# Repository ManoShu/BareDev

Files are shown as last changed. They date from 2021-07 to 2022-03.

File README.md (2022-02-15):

# BareDev - A small, yet resourceful keyboard

An open-source, QMK-compatible, ABNT2-based 70% keyboard, focusing in a smaller footprint while retaining all the functions found on a TKL (Del and arrow keys doubling as the navigational cluster)

---

Layout:

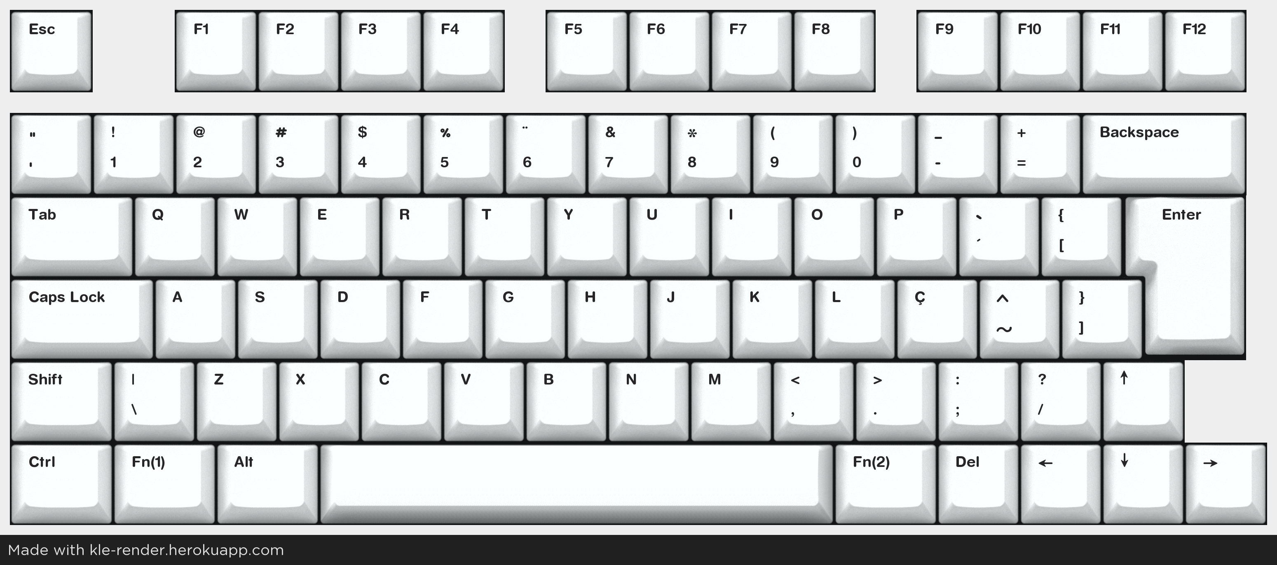
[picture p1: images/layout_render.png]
Keyboard Layout


Links: [KLE](http://www.keyboard-layout-editor.com/#/gists/89e76130aa221e028ccd5b3f6dec0909), [JSON](https://gist.github.com/ManoShu/89e76130aa221e028ccd5b3f6dec0909), [QMK](https://github.com/qmk/qmk_firmware/tree/master/keyboards/handwired/baredev/rev1)

---

## PCB & Case
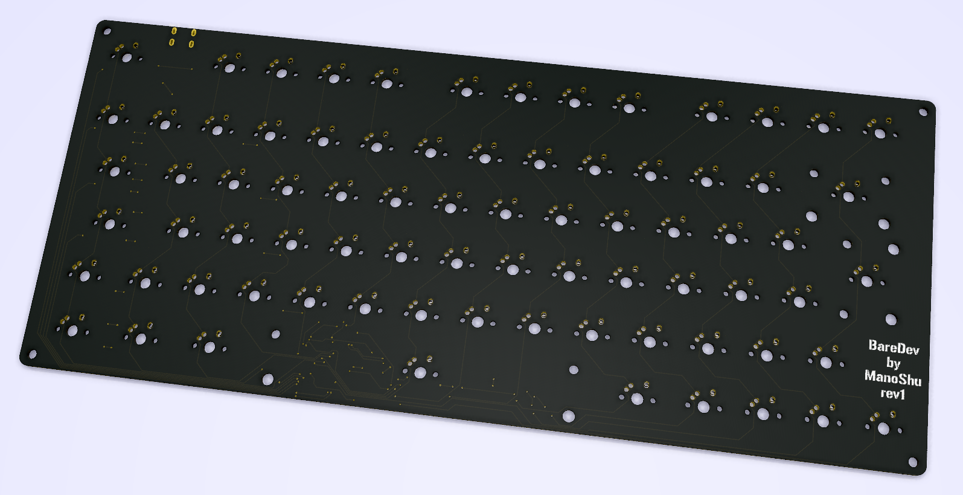
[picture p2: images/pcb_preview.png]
PCB preview on KiCad

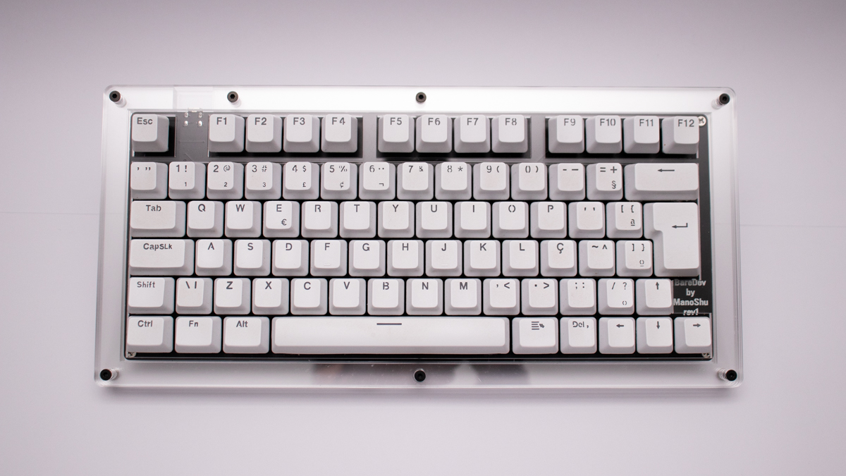
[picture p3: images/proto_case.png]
Prototype case


Note: this photo is of an early prototype of the case. The uploaded files has been updated to require less total area and WILL look slighty different than shown (the overall dimensions remain the same).

The case and gerber files are under `production`. The had been used and confirmed to work, however use them at your own risk.

## QMK

The rev1 has been integrated in the [main QMK repository](https://github.com/qmk/qmk_firmware/tree/master/keyboards/handwired/baredev/rev1), being able to use the [online configurator](https://config.qmk.fm/#/handwired/baredev/rev1/LAYOUT_abnt2) to generate the firmware while also having the files on the `qmk` directory here in case of you don't want to update your fork (HOWEVER the files have been confirmed working on QMK 0.2.2 [check yours with `qmk --version`], previous versions might not have support for some of the tags in the` info.json` file)

## VIA / VIAL

A `via` keymap is available allowing to use VIA to change keybindings without the need to setup QMK. 
It is not integrated with the official repository yet, but the .json file required to change bindings is available on the `via` directory.

A VIAL-compatible keymap is also available. It is on the official repository, but in case you don't want to update, just drop the keyboard folder to your `vial-qmk` directory and it should also work right off the bat.

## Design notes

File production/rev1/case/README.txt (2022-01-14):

To build a minimal case with a stand, cut from a 3mm thick sheet:

1 x bottom
1 x stand
2 x top

Use < 10mm screws to connect the feet to the bottom or else they might break.
Try to use flat head screws for the top as to not have them graze the hands while typing.

The height is just enough to use wrist rests very comfortably.

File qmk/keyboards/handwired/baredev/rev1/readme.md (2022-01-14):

# BareDev (rev1)

PCB
Prototype Build

An open-source, ABNT2-based 70% keyboard, focusing in a smaller footprint while retaining all the functions found on a TKL (Del and arrow keys doubling as the navigational cluster)

* Keyboard Maintainer: [Fernando "ManoShu" Rodrigues](https://github.com/ManoShu)
* Hardware Supported: BareDev rev1 PCB
* Hardware Availability: Files available on [GitHub](https://github.com/ManoShu/BareDev)

Make example for this keyboard (after setting up your build environment):

    make handwired/baredev/rev1:default

Flashing example for this keyboard:

    make handwired/baredev/rev1:default:flash

See the [build environment setup](https://docs.qmk.fm/#/getting_started_build_tools) and the [make instructions](https://docs.qmk.fm/#/getting_started_make_guide) for more information. Brand new to QMK? Start with our [Complete Newbs Guide](https://docs.qmk.fm/#/newbs).

## Bootloader

Enter the bootloader in 3 ways:

* **Bootmagic reset**: Hold down the key at (0,0) in the matrix (usually the top left key or Escape) and plug in the keyboard
* **Physical reset button**: Briefly press the button on the back of the PCB - some may have pads you must short instead
* **Keycode in layout**: Press the key mapped to `RESET` if it is available

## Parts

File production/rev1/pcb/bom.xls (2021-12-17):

Comment | Designator | Package | LCSC Part
0805W8F1002T5E | R4,R1 | R0805 | C17414
SKQGADE010 | SW1 | SKQG-1155865 | C116647
CL21A106KAYNNNE | C7 | C0805 | C15850
CL21C220JBANNNC | C2,C1 | C0805 | C1804
0805W8F220JT5E | R3,R2 | R0805 | C17561
JK-NSMD050-13.2V | F1 | Fuse_1206_3216Metric | C369159
X322516MLB4SI | Y1 | Crystal_SMD_3225-4Pin_3.2x2.5mm | C13738
1N4148W | D_0,D_1,D_2,D_3,D_4,D_5,D_6,D_7,D_8,D_9,D_10,D_11,D_12,D_13,D_14,D_15,D_16,D_17,D_18,D_19,D_20,D_21,D_22,D_23,D_24,D_25,D_26,D_27,D_28,D_29,D_30,D_31,D_32,D_33,D_34,D_35,D_36,D_37,D_38,D_39,D_40,D_41,D_42,D_43,D_44,D_45,D_46,D_47,D_48,D_49,D_50,D_51,D_52,D_53,D_54,D_55,D_56,D_57,D_58,D_59,D_60,D_61,D_62,D_63,D_64,D_65,D_66,D_67,D_68,D_69,D_70,D_71,D_72,D_73,D_74,D_75,D_76 | D_SOD-123 | C81598
548190589 | USB1 | MINI-USB-SMD | C505284
CL21B105KBFNNNE | C3 | C0805 | C28323
CC0805KRX7R9BB104 | C6,C5,C4 | C0805 | C49678
ATMEGA32U4-AU | U1 | TQFP-44_10x10mm_P0.8mm | C44854

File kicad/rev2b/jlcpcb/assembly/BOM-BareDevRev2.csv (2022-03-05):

Comment | Designator | Footprint | LCSC
GZ2012D601TF | FB401 | L_0805_2012Metric | C1017
BL24C256A-SFRC | U1 | TSSOP-8_4.4x3mm_P0.65mm | C110276
100k | R201,R202 | R_0805_2012Metric | C149504
AO3401A | Q1 | SOT-23 | C15127
10n | C203,C7 | C_0402_1005Metric | C15195
100n | C1,C10,C2,C3,C302,C4 | C_0402_1005Metric | C1525
10u | C301 | C_0402_1005Metric | C15525
TYPE-C-31-M12 | J401 | USB_C_Receptacle_Hroparts_TYPE-C-31-M-12 | C165948
10k | R308,R6 | R_0805_2012Metric | C17414
2k | R101,R102,R103,R104,R105,R106,R107,R108,R109,R110,R111,R112,R113,R114,R115,R116,R117,R118,R119,R120,R121,R122,R123,R124,R125,R126,R127,R128,R129,R130,R131,R132,R133,R134,R135,R136,R137,R138,R139,R140,R141,R142,R143,R144,R145,R146,R147,R148,R149,R150,R151,R152,R153,R154,R155,R156,R157,R158,R159,R160,R161,R162,R163,R164,R165,R166,R167,R168,R169,R170,R171,R172,R173,R174,R175,R176,R177 | R_0805_2012Metric | C17604
470 | R7 | R_0805_2012Metric | C17710
SGM2007-3.3XN5/TR | U201 | SOT-23-5 | C193687
4.7u | C11 | C_0402_1005Metric | C23733
100R | R304,R305,R306 | R_0402_1005Metric | C25076
10k | R303,R307 | R_0402_1005Metric | C25744
330k | R301 | R_0402_1005Metric | C25778
4.7k | R1,R2 | R_0402_1005Metric | C25900
5.1k | R401,R402 | R_0402_1005Metric | C25905
1M | R302 | R_0402_1005Metric | C26083
USBLC6-2SC6 | U3 | SOT-23-6 | C2827654
1u | C201,C202 | C_0805_2012Metric | C28323
7325-0800A2010-00 | Y1 | Crystal_SMD_3225-4Pin_3.2x2.5mm | C389817
16p | C8,C9 | C_0402_1005Metric | C48836
1u | C6 | C_0402_1005Metric | C52923
JOKER MCU | U2 | STM_UFQFPN-48_LQFP-48-1EP_7x7mm_P0.5mm_HandSoldering_ThermalReliefs | C60420
nSMD100-16V | F201 | Fuse_1206_3216Metric | C70082
10u | C5 | CP_EIA-3216-10_Kemet-I_Pad1.58x1.35mm_HandSolder | C7171
1N4148W | D301,D_101,D_102,D_103,D_104,D_105,D_106,D_107,D_108,D_109,D_110,D_111,D_112,D_113,D_114,D_115,D_116,D_117,D_118,D_119,D_120,D_121,D_122,D_123,D_124,D_125,D_126,D_127,D_128,D_129,D_130,D_131,D_132,D_133,D_134,D_135,D_136,D_137,D_138,D_139,D_140,D_141,D_142,D_143,D_144,D_145,D_146,D_147,D_148,D_149,D_150,D_151,D_152,D_153,D_154,D_155,D_156,D_157,D_158,D_159,D_160,D_161,D_162,D_163,D_164,D_165,D_166,D_167,D_168,D_169,D_170,D_171,D_172,D_173,D_174,D_175,D_176,D_177 | D_SOD-123 | C81598
2N7002 | Q301,Q302 | SOT-23 | C8545
B5819W-SL | D201 | D_SOD-123 | C8598
K2-1187SQ-A4SW-06 | SW301 | K2-1187SQ-A4SW-06 | C92584

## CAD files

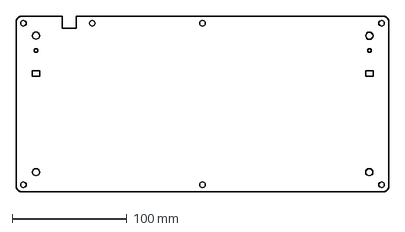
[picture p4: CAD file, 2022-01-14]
production/rev1/case/bottom.dxf
324.5 x 153.1 mm

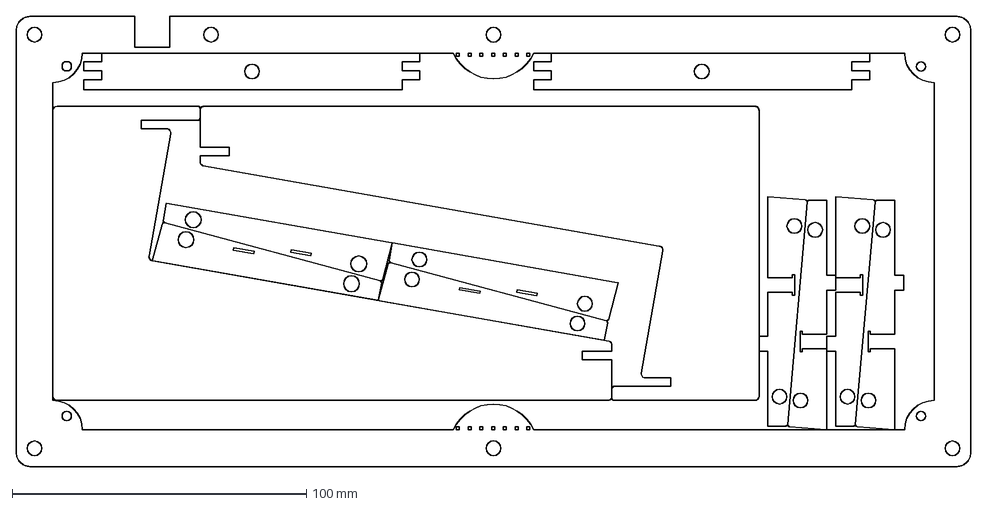
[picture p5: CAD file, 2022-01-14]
production/rev1/case/stand.dxf
324.5 x 153.1 mm

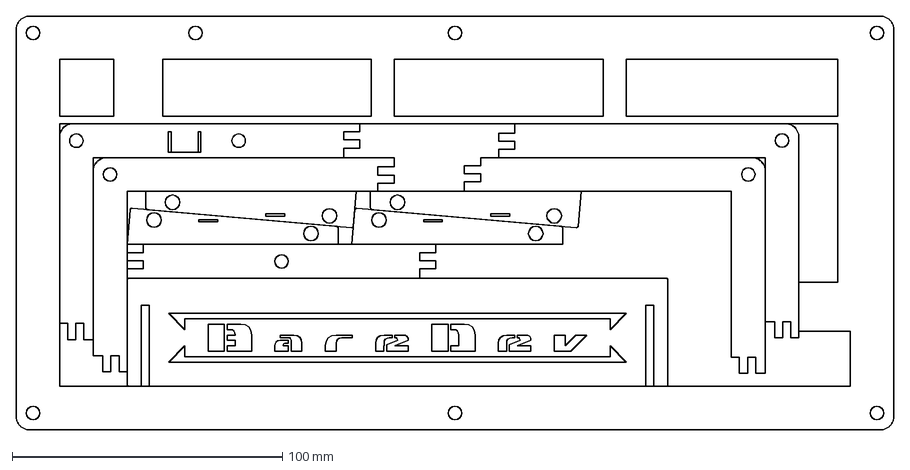
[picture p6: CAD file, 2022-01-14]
production/rev1/case/top.dxf
324.5 x 153.1 mm

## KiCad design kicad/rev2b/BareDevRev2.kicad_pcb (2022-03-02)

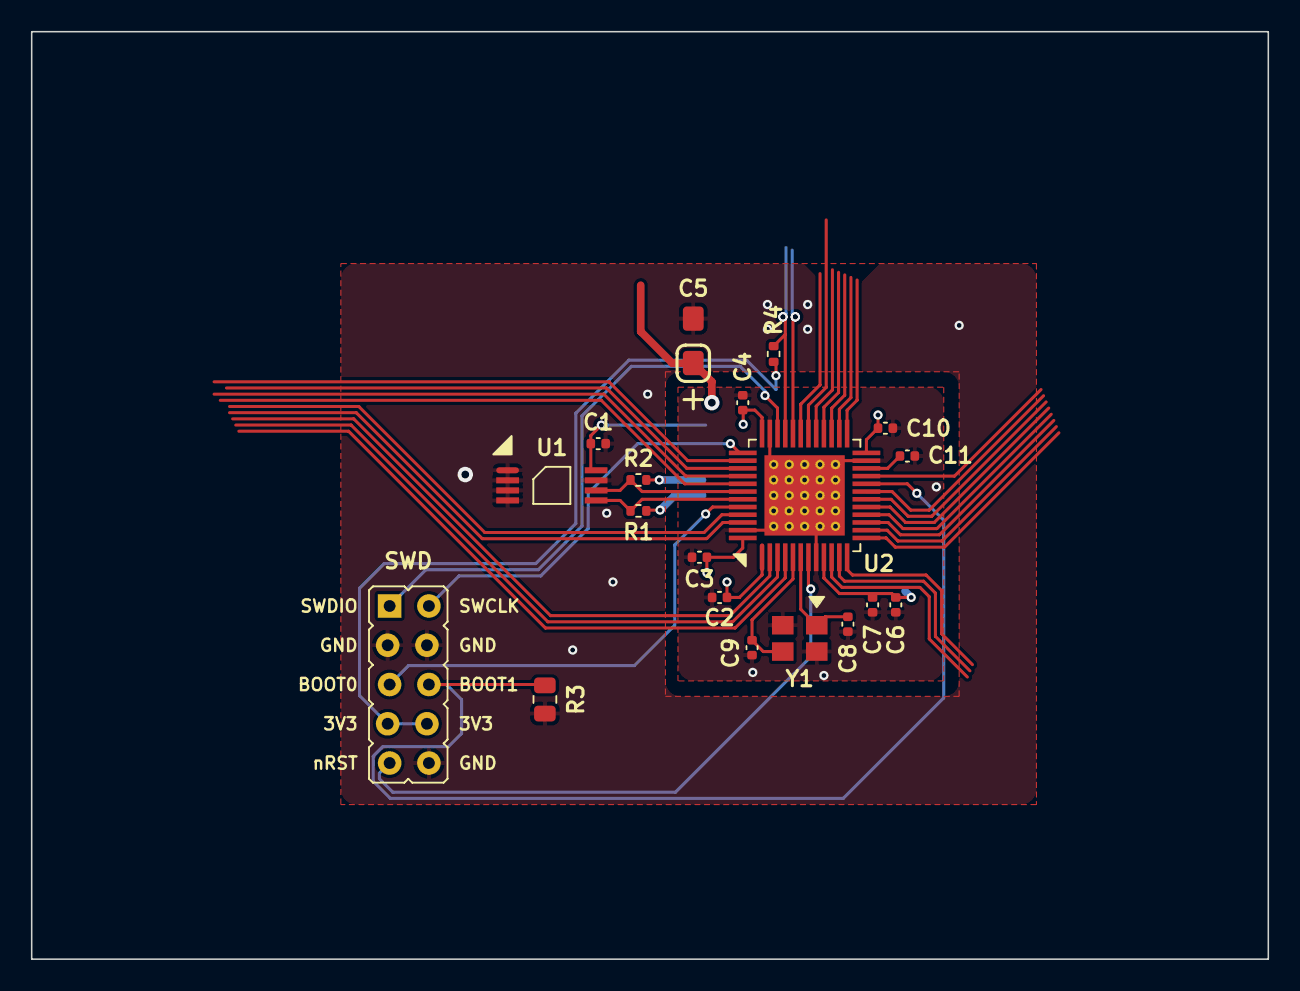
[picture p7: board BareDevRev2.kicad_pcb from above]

Board: 2 copper layers, 80.0 x 60.0 mm, 19 parts (0 on the bottom side), 13 nets.

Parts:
C1, C2, C3, C4, C10: 100n; C_0402_1005Metric
C5: 10u; CP_EIA-3216-10_Kemet-I_Pad1.58x1.35mm_HandSolder
C6: 1u; C_0402_1005Metric
C7: 10n; C_0402_1005Metric
C8, C9: 16p; C_0402_1005Metric
C11: 4.7u; C_0402_1005Metric
R1, R2, R4: 1.5k; R_0402_1005Metric
R3: 10k; R_0805_2012Metric
U1: BL24C256A-SFRC; TSSOP-8_4.4x3mm_P0.65mm
U2: STM32F411CEU6; STM_UFQFPN-48_LQFP-48-1EP_7x7mm_P0.5mm_HandSoldering_Therma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
X1: ARM JTAG; PinHeader_2x5_P2.54mm_Vertical_Staggered
Y1: 7325-0800A2010-00; Crystal_SMD_3225-4Pin_3.2x2.5mm

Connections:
3V3: C1.2, C2.1, C3.1, C4.2, C5.1, C6.1, C7.1, C10.2, R1.1, R2.1, R4.1, U1.8 (VCC), U2.1 (VBAT), U2.9 (VDDA/VREF+), U2.24 (VDD), U2.36 (VDD), U2.48 (VDD), X1.7, X1.8
BOOT0: U2.44 (BOOT0), X1.5
D+: R4.2, U2.33 (PA12/USB_FS_DP)
GND: C1.1, C2.2, C3.2, C4.1, C5.2, C6.2, C7.2, C8.2, C9.2, C10.1, C11.1, R3.2, U1.1 (A0), U1.2 (A1), U1.3 (A2), U1.4 (GND), U1.7 (WP), U2.8 (VSSA), U2.23 (VSS), U2.35 (VSS), U2.47 (VSS), X1.3, X1.4, X1.10, Y1.2, Y1.4
NRST: U2.7 (NRST), X1.9
unnamed: C11.2, U2.22 (VCAP_1)
PB2/BOOT1: R3.1, U2.20 (PB2), X1.6
SCL: R2.2, U1.6 (SCL), U2.42 (PB6/I2C1_SCL)
SDA: R1.2, U1.5 (SDA), U2.43 (PB7/I2C1_SDA)
SWCLK: U2.37 (PA14/SWCLK), X1.2
SWDIO: U2.34 (PA12/SWDIO), X1.1
XTAL_IN: C9.1, U2.5 (PH0_OSCIN), Y1.3
XTAL_OUT: C8.1, U2.6 (PH1_OSCOUT), Y1.1

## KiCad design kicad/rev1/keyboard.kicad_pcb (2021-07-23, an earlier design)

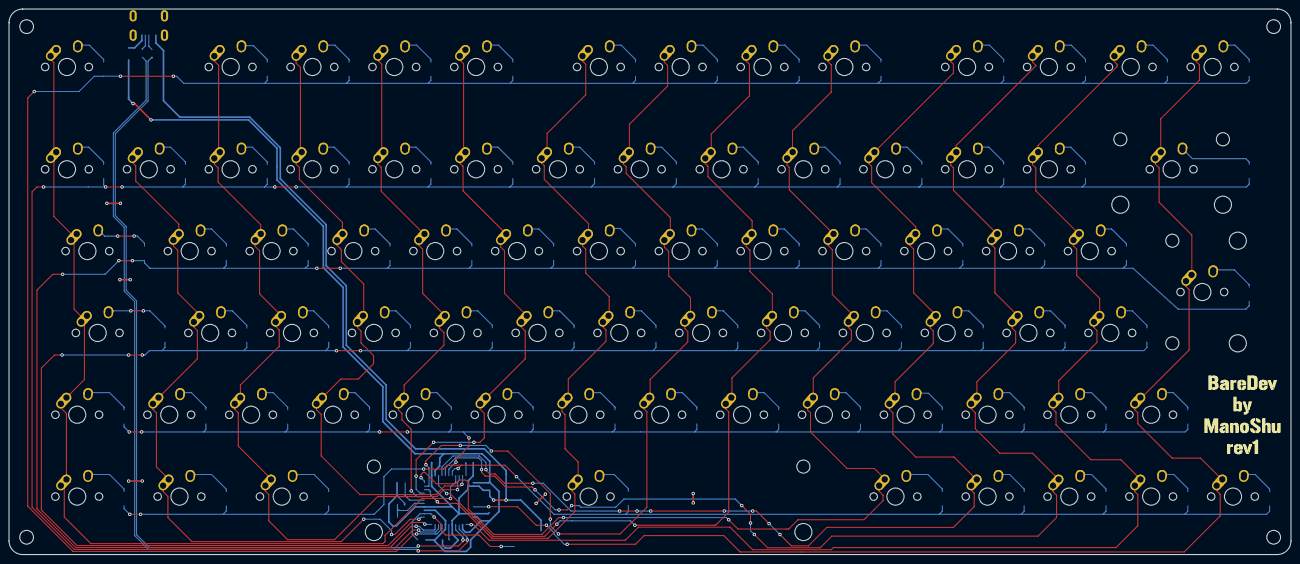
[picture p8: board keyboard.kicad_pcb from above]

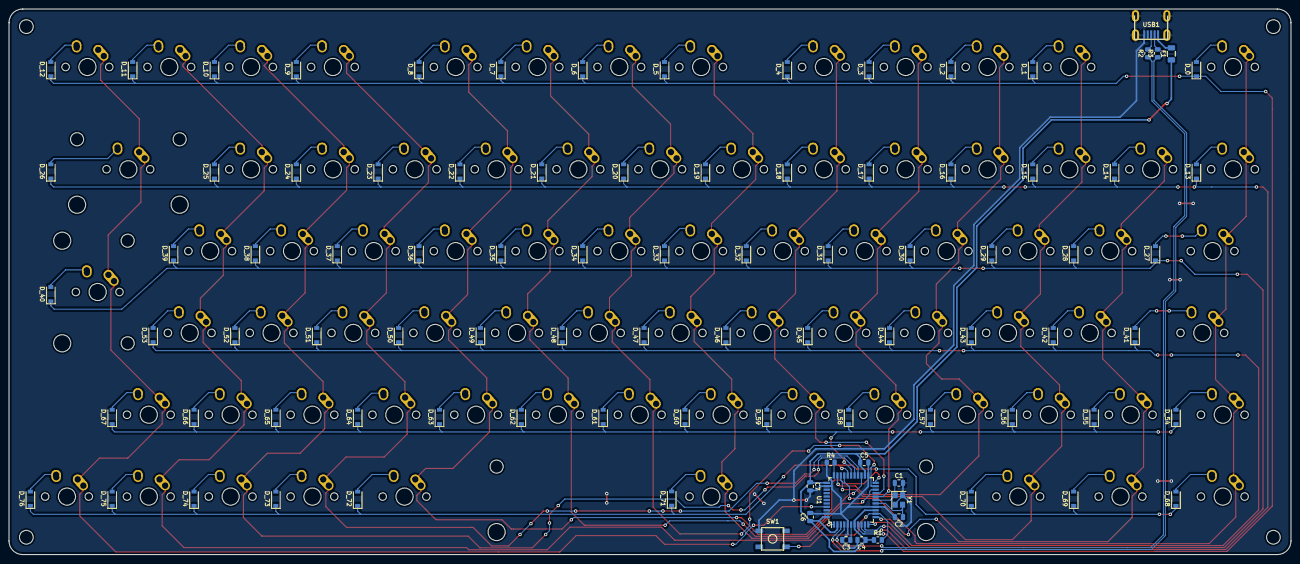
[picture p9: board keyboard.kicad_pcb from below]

Board: 2 copper layers, 298.4 x 127.0 mm, 171 parts (93 on the bottom side), 109 nets.

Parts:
BAREDEV_LOGO: BAREDEV_LOGO
C1, C2: 22pF; C_0805_2012Metric
C3: 1uF; C_0805_2012Metric
C4, C5, C6: 0.1uF; C_0805_2012Metric
C7: 10uF; C_0805_2012Metric
D_0, D_1, D_2, D_3, D_4, D_5, D_6, D_7, D_8, D_9, D_10, D_11, D_12, D_13, D_14, D_15, D_16, D_17, D_18, D_19, D_20, D_21, D_22, D_23, D_24, D_25, D_26, D_27, D_28, D_29, D_30, D_31, D_32, D_33, D_34, D_35, D_36, D_37, D_38, D_39, D_40, D_41, D_42, D_43, D_44, D_45, D_46, D_47, D_48, D_49, D_50, D_51, D_52, D_53, D_54, D_55, D_56, D_57, D_58, D_59, D_60, D_61, D_62, D_63, D_64, D_65, D_66, D_67, D_68, D_69, D_70, D_71, D_72, D_73, D_74, D_75, D_76: D; D_SOD-123
F1: 500mA; Fuse_1206_3216Metric
K_0, K_1, K_2, K_3, K_4, K_5, K_6, K_7, K_8, K_9, K_10, K_11, K_12, K_13, K_14, K_15, K_16, K_17, K_18, K_19, K_20, K_21, K_22, K_23, K_24, K_25, K_28, K_29, K_30, K_31, K_32, K_33, K_34, K_35, K_36, K_37, K_38, K_39, K_42, K_43, K_44, K_45, K_46, K_47, K_48, K_49, K_50, K_51, K_52, K_53, K_55, K_56, K_57, K_58, K_59, K_60, K_61, K_62, K_63, K_64, K_65, K_66, K_67, K_73, K_74, K_75, K_76: KEYSW; MX-1U-NoLED
K_26: KEYSW; MX-2U-NoLED
K_27: KEYSW; MX-1.5U-NoLED
K_40: KEYSW; MX-ISOEnter-NoLED
K_41: KEYSW; MX-1.75U-NoLED
K_54, K_68, K_69, K_70, K_72: KEYSW; MX-1.25U-NoLED
K_71: KEYSW; MX-6.25U-NoLED
R1, R4: 10k; R_0805_2012Metric
R2, R3: 22; R_0805_2012Metric
SW1: SW_Push; SKQG-1155865
U1: ATmega32U4-AU; TQFP-44_10x10mm_P0.8mm
USB1: Molex-0548190589
Y1: 16MHz; Crystal_SMD_3225-4Pin_3.2x2.5mm

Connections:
+5V: C4.1, C5.1, C6.1, C7.1, F1.1, R1.1, U1.2, U1.7, U1.14, U1.24, U1.34, U1.44
D+: R2.2, USB1.3
D-: R3.2, USB1.4
GND: C1.2, C2.2, C3.2, C4.2, C5.2, C6.2, C7.2, R4.1, SW1.1, U1.5, U1.15, U1.23, U1.35, U1.43, USB1.1, USB1.6, Y1.2, Y1.4
unnamed: C1.1, U1.17, Y1.1
unnamed: C2.1, U1.16, Y1.3
unnamed: C3.1, U1.6
unnamed: D_0.2, K_0.2
unnamed: D_1.2, K_1.2
unnamed: D_2.2, K_2.2
unnamed: D_3.2, K_3.2
unnamed: D_4.2, K_4.2
unnamed: D_5.2, K_5.2
unnamed: D_6.2, K_6.2
unnamed: D_7.2, K_7.2
unnamed: D_8.2, K_8.2
unnamed: D_9.2, K_9.2
unnamed: D_10.2, K_10.2
unnamed: D_11.2, K_11.2
unnamed: D_12.2, K_12.2
unnamed: D_13.2, K_13.2
unnamed: D_14.2, K_14.2
unnamed: D_15.2, K_15.2
unnamed: D_16.2, K_16.2
unnamed: D_17.2, K_17.2
unnamed: D_18.2, K_18.2
unnamed: D_19.2, K_19.2
unnamed: D_20.2, K_20.2
unnamed: D_21.2, K_21.2
unnamed: D_22.2, K_22.2
unnamed: D_23.2, K_23.2
unnamed: D_24.2, K_24.2
unnamed: D_25.2, K_25.2
unnamed: D_26.2, K_26.2
unnamed: D_27.2, K_27.2
unnamed: D_28.2, K_28.2
unnamed: D_29.2, K_29.2
unnamed: D_30.2, K_30.2
unnamed: D_31.2, K_31.2
unnamed: D_32.2, K_32.2
unnamed: D_33.2, K_33.2
unnamed: D_34.2, K_34.2
unnamed: D_35.2, K_35.2
unnamed: D_36.2, K_36.2
unnamed: D_37.2, K_37.2
unnamed: D_38.2, K_38.2
unnamed: D_39.2, K_39.2
unnamed: D_40.2, K_40.2
unnamed: D_41.2, K_41.2
unnamed: D_42.2, K_42.2
unnamed: D_43.2, K_43.2
unnamed: D_44.2, K_44.2
unnamed: D_45.2, K_45.2
unnamed: D_46.2, K_46.2
unnamed: D_47.2, K_47.2
unnamed: D_48.2, K_48.2
unnamed: D_49.2, K_49.2
unnamed: D_50.2, K_50.2
unnamed: D_51.2, K_51.2
unnamed: D_52.2, K_52.2
unnamed: D_53.2, K_53.2
unnamed: D_54.2, K_54.2
unnamed: D_55.2, K_55.2
unnamed: D_56.2, K_56.2
unnamed: D_57.2, K_57.2
unnamed: D_58.2, K_58.2
unnamed: D_59.2, K_59.2
unnamed: D_60.2, K_60.2
unnamed: D_61.2, K_61.2
unnamed: D_62.2, K_62.2
unnamed: D_63.2, K_63.2
unnamed: D_64.2, K_64.2
unnamed: D_65.2, K_65.2
unnamed: D_66.2, K_66.2
unnamed: D_67.2, K_67.2
unnamed: D_68.2, K_68.2
unnamed: D_69.2, K_69.2
unnamed: D_70.2, K_70.2
unnamed: D_71.2, K_71.2
unnamed: D_72.2, K_72.2
unnamed: D_73.2, K_73.2
unnamed: D_74.2, K_74.2
unnamed: D_75.2, K_75.2
unnamed: D_76.2, K_76.2
unnamed: R1.2, SW1.2, U1.13
unnamed: R2.1, U1.4
unnamed: R3.1, U1.3
unnamed: R4.2, U1.33
VCC: F1.2, USB1.5
col0: K_0.1, K_13.1, K_27.1, K_41.1, K_54.1, K_68.1, U1.30
col1: K_14.1, K_28.1, K_42.1, K_55.1, K_69.1, U1.12
col2: K_1.1, K_15.1, K_29.1, K_43.1, K_56.1, K_70.1, U1.31
col3: K_2.1, K_16.1, K_30.1, K_44.1, K_57.1, U1.32
col4: K_3.1, K_17.1, K_31.1, K_45.1, K_58.1, U1.18
col5: K_4.1, K_18.1, K_32.1, K_46.1, K_59.1, U1.19
col6: K_5.1, K_19.1, K_33.1, K_47.1, K_60.1, K_71.1, U1.20
col7: K_6.1, K_20.1, K_34.1, K_48.1, K_61.1, U1.21
col8: K_7.1, K_21.1, K_35.1, K_49.1, K_62.1, U1.25
col9: K_8.1, K_22.1, K_36.1, K_50.1, K_63.1, K_72.1, U1.22
col10: K_9.1, K_23.1, K_37.1, K_51.1, K_64.1, K_73.1, U1.26
col11: K_10.1, K_24.1, K_38.1, K_52.1, K_65.1, K_74.1, U1.27
col12: K_11.1, K_25.1, K_39.1, K_53.1, K_66.1, K_75.1, U1.1
col13: K_12.1, K_26.1, K_40.1, K_67.1, K_76.1, U1.41
row0: D_0.1, D_1.1, D_2.1, D_3.1, D_4.1, D_5.1, D_6.1, D_7.1, D_8.1, D_9.1, D_10.1, D_11.1, D_12.1, U1.8
row1: D_13.1, D_14.1, D_15.1, D_16.1, D_17.1, D_18.1, D_19.1, D_20.1, D_21.1, D_22.1, D_23.1, D_24.1, D_25.1, D_26.1, U1.9
row2: D_27.1, D_28.1, D_29.1, D_30.1, D_31.1, D_32.1, D_33.1, D_34.1, D_35.1, D_36.1, D_37.1, D_38.1, D_39.1, D_40.1, U1.10
row3: D_41.1, D_42.1, D_43.1, D_44.1, D_45.1, D_46.1, D_47.1, D_48.1, D_49.1, D_50.1, D_51.1, D_52.1, D_53.1, U1.11
row4: D_54.1, D_55.1, D_56.1, D_57.1, D_58.1, D_59.1, D_60.1, D_61.1, D_62.1, D_63.1, D_64.1, D_65.1, D_66.1, D_67.1, U1.28
row5: D_68.1, D_69.1, D_70.1, D_71.1, D_72.1, D_73.1, D_74.1, D_75.1, D_76.1, U1.29

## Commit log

2021-07-15 Adding base kicad files (not working yet)
    [keyboard.kicad_pcb, keyboard.sch]
2021-07-22 Updated project
    [keyboard.kicad_pcb, keyboard.sch]
2021-07-22 Schematic complete
    [keyboard.sch]
2021-07-23 1st version of PCB complete
    [keyboard.kicad_pcb, keyboard.sch]
2021-07-23 Revised traces
    [keyboard.kicad_pcb]
2021-07-23 Added production files and added text to PCB
    [bom.xls, keyboard.kicad_pcb, plate.dxf]
2021-07-23 Added position file
    [keyboard-all-pos.csv]
2021-07-24 Fixed BOM to use reference the correct connector
    [bom.xls]
2021-07-24 Updated part name for USB connector
    [bom.xls]
2021-07-24 Added v2 directory
    [keyboard.kicad_pcb, keyboard.sch]
2021-07-26 v2 board DRC cleared
    [keyboard.kicad_pcb, keyboard.sch]
2021-07-26 Added text
    [keyboard.kicad_pcb]
2021-12-17 Directory tree rework to start rev2 development
    Former-commit-id: 18c596bd722c1b8838767bc8a1715bf582b47f4a
    [bom.xls, keyboard.kicad_pcb, keyboard.sch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]
2022-01-14 Uploaded QMK and case files; README update
    Former-commit-id: 6f7f39cc7777f5bec9c2551d6fcce16e323bc2d0
    [bottom.dxf, keyboard.kicad_sch, stand.dxf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]
2022-02-18 Fixed missing 'Don't connect's in schematic
    [keyboard.kicad_sch]
2022-02-18 Initial rev2 development
    [keyboard.kicad_sch, keyboard.sch]
2022-02-21 rev2 base PCB done
    [keyboard.kicad_sch]
2022-02-21 base rev2 PCB done
    [keyboard.kicad_sch]
2022-02-22 rev2 PCB finished
    [keyboard.kicad_sch]
2022-02-22 Applied major silk screen drawings
    [keyboard.kicad_sch]
2022-03-02 Updated PCB file
2022-03-02 Renaming rev2 folder to work on a STM version
    [keyboard.kicad_sch, keyboard.sch]
2022-03-02 Adding rev2b base files
    [BareDevRev2.kicad_pcb, BareDevRev2.kicad_sch]
2022-03-02 Updated .gitmodules (???)
    [BareDevRev2.kicad_sch]
2022-03-02 initial rev2b schematic
    [BareDevRev2.kicad_pcb, BareDevRev2.kicad_sch]
2022-03-03 Refactored matrix and LED grids
    [BareDevRev2.kicad_sch]
2022-03-04 (WIP) rev2b work
    [BareDevRev2.kicad_sch]
2022-03-04 rev2b routing done (production files not working with JLCPCB
    [BareDevRev2-B_Cu.gbr, BareDevRev2-B_Mask.gbr, BareDevRev2-B_Paste.gbr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]
2022-03-04 Removing unreliable production files
    [BareDevRev2-B_Cu.gbr, BareDevRev2-B_Mask.gbr, BareDevRev2-B_Paste.gbr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]
2022-03-05 Added production files (not yet confirmed working)
    [BareDevRev2-CuBottom.gbr, BareDevRev2-CuTop.gbr, BareDevRev2-EdgeCuts.gbr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]
2022-03-05 Adding assembly files (not yet tested)
    [BOM-BareDevRev2.csv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]
2022-03-06 Art vector inserted (sadly overlapping)
    [BareDevRev2-CuBottom.gbr, BareDevRev2-CuTop.gbr, BareDevRev2-EdgeCuts.gbr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]
2022-03-07 Updated production files
    [BareDevRev2-CuBottom.gbr, BareDevRev2-CuTop.gbr, BareDevRev2-EdgeCuts.gbr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]
